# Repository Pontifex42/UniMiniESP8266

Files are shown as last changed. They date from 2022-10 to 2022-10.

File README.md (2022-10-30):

# UniMiniESP8266

For common simple microcontroller applications, I created a very tiny board in the size of an 18650 cell.
In many cases, the 3,0V - 4,2V of a single cell is sufficient, which makes it extremely simple to build working circuits.
There are many pins for power supply, so there is no more breadbord wiring or perfboard wiring hell.

What it can do for you:
- easyly powered with a single 18650 lithium cell, works down to 3,2V discharge due to LDO
- drives up to 6 servos (using 18650 voltage)
- has two pins with transitor-outputs, if populated
- can have an H-bridge using L9110
- onboard switch intended (or use a solder bridge)
- WiFi ability due to the power of ESP8266

To download code, use a FTDI-adapter, shorten pin M1 to ground and press reset or, if reset switch is not populated, just power on.

As an example, have a look in my "Servo-Tester" repository on github:
https://github.com/Pontifex42/ServoTester

It uses ESP8266-12F module, I will create an improved version using ESP-C3-12F soon.

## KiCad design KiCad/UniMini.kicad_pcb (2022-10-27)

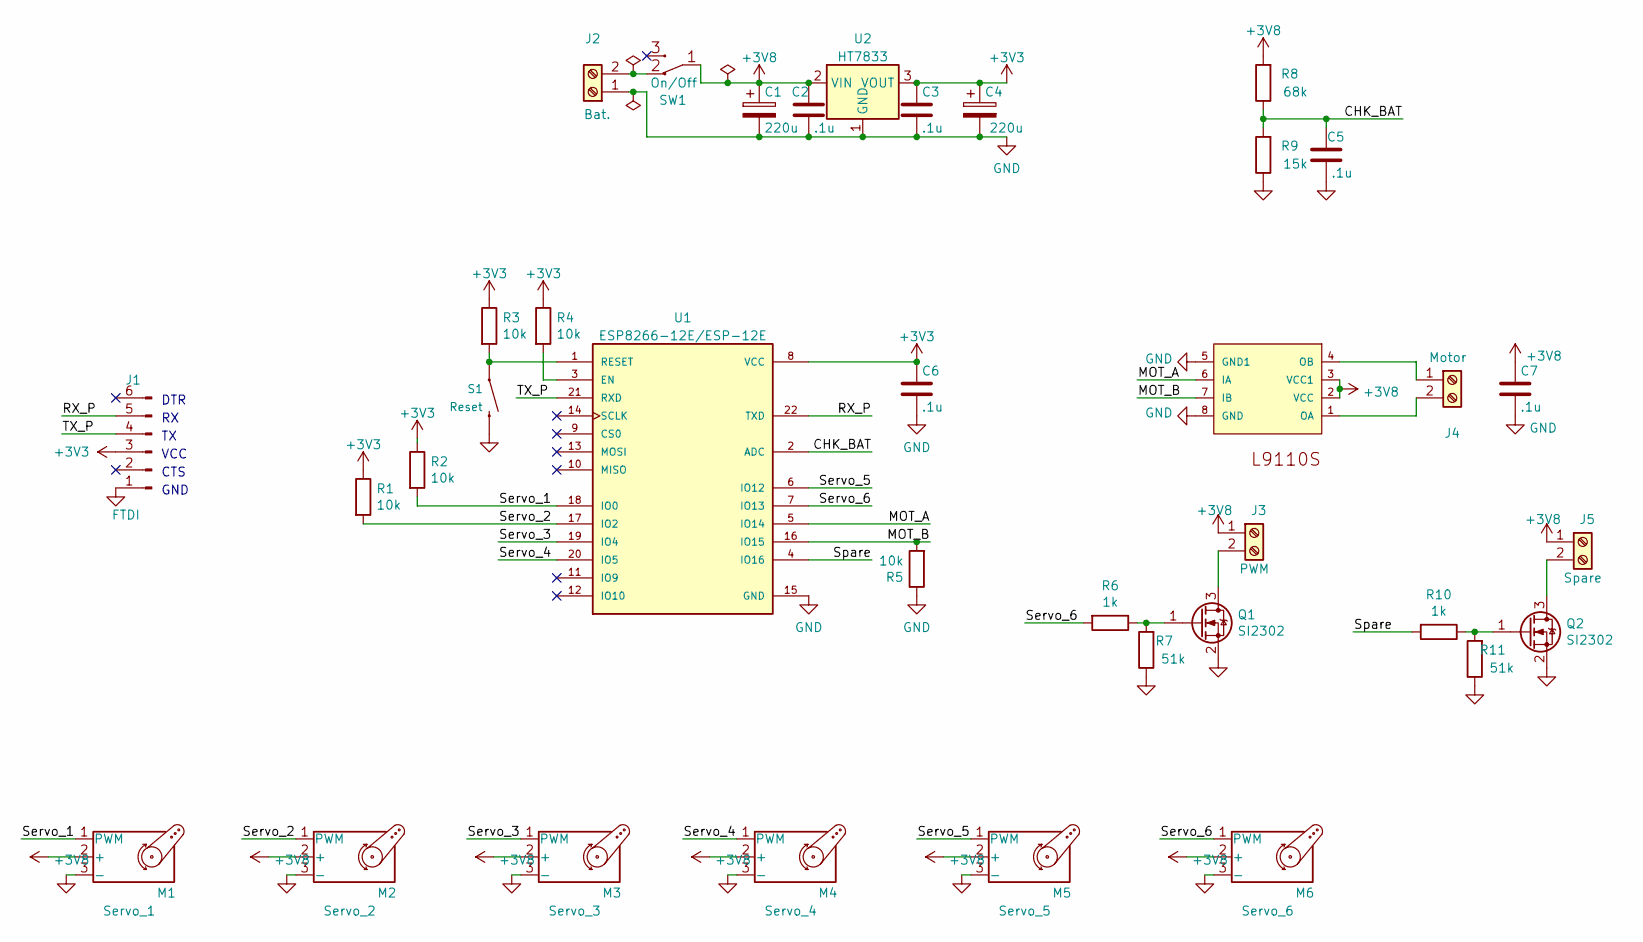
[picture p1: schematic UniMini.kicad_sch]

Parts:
C1, C4: 220u; CP_Elec_8x10.5
C2, C3, C5, C6, C7: .1u; C_0805_2012Metric_Pad1.18x1.45mm_HandSolder
J1: FTDI; PinHeader_1x06_P2.54mm_Vertical
J2: Bat.; PinHeader_1x02_P2.54mm_Vertical
J3: PWM; PinHeader_1x02_P2.54mm_Vertical
J4: Motor; PinHeader_1x02_P2.54mm_Vertical
J5: Spare; PinHeader_1x02_P2.54mm_Vertical
M1: Servo_1; PinHeader_1x03_P2.54mm_Vertical
M2: Servo_2; PinHeader_1x03_P2.54mm_Vertical
M3: Servo_3; PinHeader_1x03_P2.54mm_Vertical
M4: Servo_4; PinHeader_1x03_P2.54mm_Vertical
M5: Servo_5; PinHeader_1x03_P2.54mm_Vertical
M6: Servo_6; PinHeader_1x03_P2.54mm_Vertical
Q1, Q2: SI2302; SOT-23
R1, R2, R3, R4, R5: 10k; R_0805_2012Metric_Pad1.20x1.40mm_HandSolder
R6, R10: 1k; R_0805_2012Metric_Pad1.20x1.40mm_HandSolder
R7, R11: 51k; R_0805_2012Metric_Pad1.20x1.40mm_HandSolder
R8: 68k; R_0805_2012Metric_Pad1.20x1.40mm_HandSolder
R9: 15k; R_0805_2012Metric_Pad1.20x1.40mm_HandSolder
S1: Reset; TACTILE_SWITCH_SMD_6.0X3.5MM
SW1: On/Off; MST-22D01_Standing
U1: ESP8266-12E/ESP-12E; XCVR_ESP8266-12E_ESP-12E
U2: HT7833; SOT-89-3
U3: L9110S; SOIC127P600X150-8

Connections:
+3V3: C3.1, C4.1, C6.1, J1.3, R1.1, R2.1, R3.1, R4.1, U1.8 (VCC), U2.3 (VOUT)
+3V8: C1.1, C2.1, C7.1, J3.1, J5.1, M1.2 (+), M2.2 (+), M3.2 (+), M4.2 (+), M5.2 (+), M6.2 (+), R8.2, SW1.1 (COM), U2.2 (VIN), U3.2 (VCC), U3.3 (VCC1)
/CHK_BAT: C5.1, R8.1, R9.2, U1.2 (ADC)
/MOT_A: U1.5 (IO14), U3.6 (IA)
/MOT_B: R5.2, U1.16 (IO15), U3.7 (IB)
/RX_P: J1.5, U1.22 (TXD)
/Servo_1: M1.1 (PWM), R2.2, U1.18 (IO0)
/Servo_2: M2.1 (PWM), R1.2, U1.17 (IO2)
/Servo_3: M3.1 (PWM), U1.19 (IO4)
/Servo_4: M4.1 (PWM), U1.20 (IO5)
/Servo_5: M5.1 (PWM), U1.6 (IO12)
/Servo_6: M6.1 (PWM), R6.2, U1.7 (IO13)
/Spare: R10.2, U1.4 (IO16)
/TX_P: J1.4, U1.21 (RXD)
GND: C1.2, C2.2, C3.2, C4.2, C5.2, C6.2, C7.2, J1.1, J2.1, M1.3 (-), M2.3 (-), M3.3 (-), M4.3 (-), M5.3 (-), M6.3 (-), Q1.2 (S), Q2.2 (S), R5.1, R7.1, R9.1, R11.1, S1.2, U1.15 (GND), U2.1 (GND), U3.5 (GND1), U3.8 (GND)
unnamed: J2.2, SW1.2 (NC)
unnamed: J3.2, Q1.3 (D)
unnamed: J4.1, U3.4 (OB)
unnamed: J4.2, U3.1 (OA)
unnamed: J5.2, Q2.3 (D)
unnamed: Q1.1 (G), R6.1, R7.2
unnamed: Q2.1 (G), R10.1, R11.2
unnamed: R3.2, S1.1, U1.1 (RESET)
unnamed: R4.2, U1.3 (EN)

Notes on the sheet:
DTR
VCC
CTS
GND

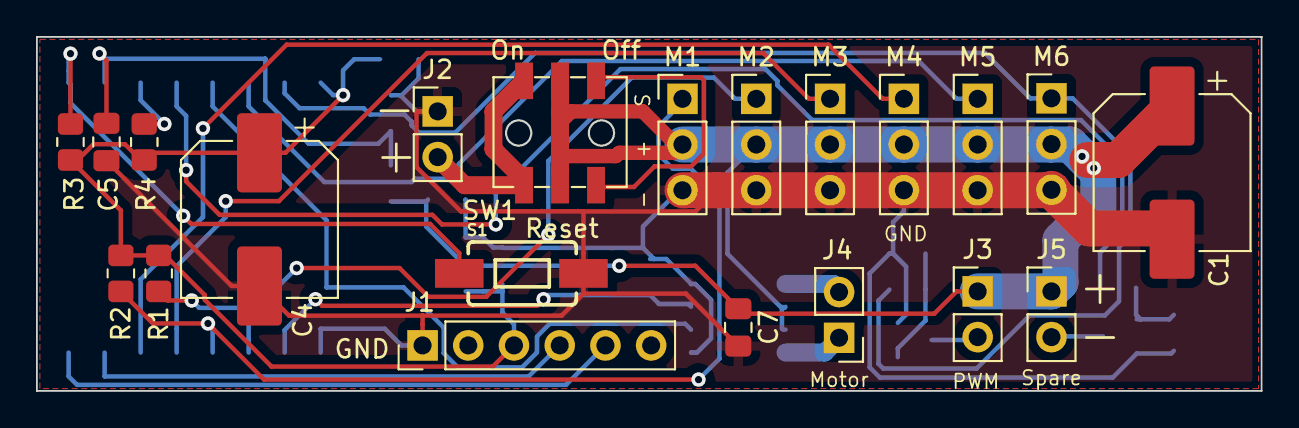
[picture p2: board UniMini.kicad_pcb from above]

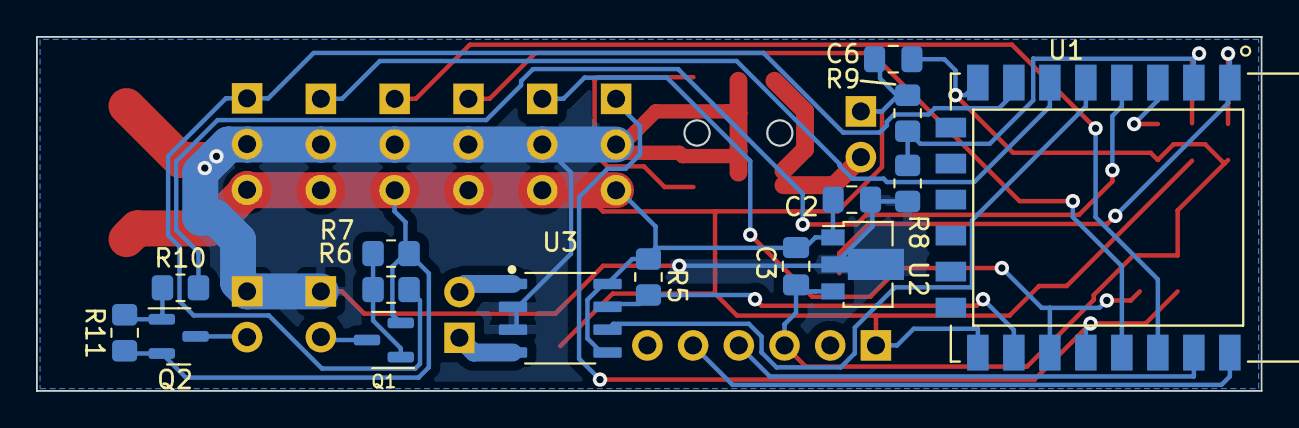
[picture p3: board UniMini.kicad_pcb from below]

Board: 2 copper layers, 68.0 x 19.7 mm, 36 parts (15 on the bottom side), 24 nets.
